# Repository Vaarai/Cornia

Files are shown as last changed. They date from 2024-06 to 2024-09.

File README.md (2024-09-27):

<h1 align="center">
 
</h1>

# Cornia keyboard

<h1 align="center">
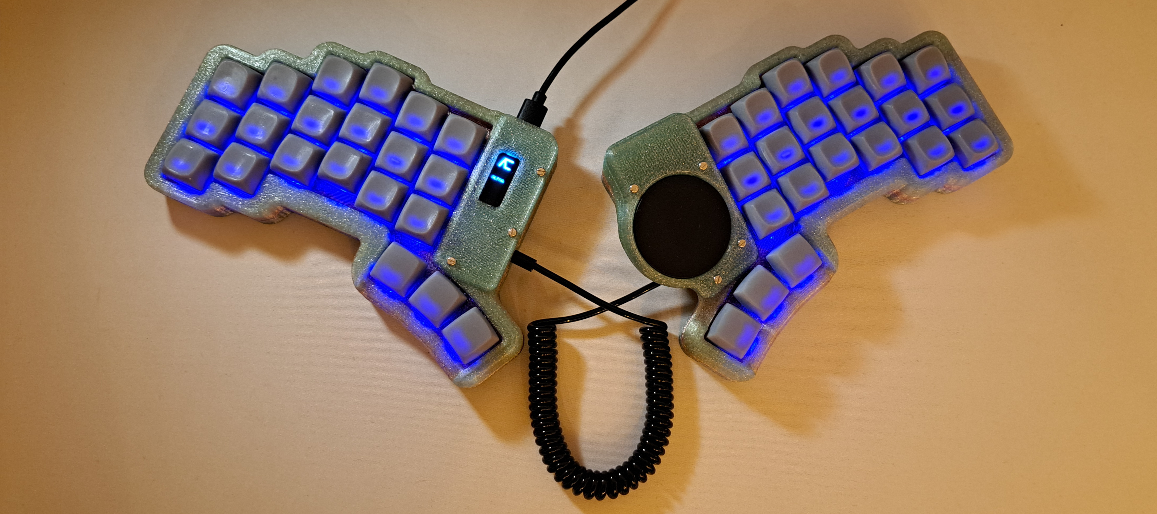
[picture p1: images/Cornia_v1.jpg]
 
</h1>

The Cornia keyboard is a split keyboard featuring : 
* 3x6 column strongly staggered keys and 3 thumb keys
* Hotswap sockets (Compatible with Kailh and Gateron)
* All 1u keys
* Same PCB for both hands (revesible)
* No diode to solder (No switch matrix)
* Per key adressable RGB leds (SK6812MINI-E)
* QMK Handedness pin (see [QMK documentation](https://github.com/qmk/qmk_firmware/blob/master/docs/config_options.md#setting-handedness))

### Why this name ?

Because it was inspired from the [Corne](https://github.com/foostan/crkbd/tree/main) keyboard, and `Cornia` came in mind.

### Table of contents

<!--ts-->
  * [Quick steps](#quick-steps)
  * [Hardware](#hardware)
    * [Bill of material](#bill-of-material)
    * [Compatible controllers](#compatible-controllers)
    * [PCB Design](#pcb-design-and-manufacturing)
    * [Keyboard assembling](#keyboard-assembling)
    * [Troubleshooting](#troubleshooting)
  * [Software](#software)
    * [Cornia not yet integrated in official QMK ?](#cornia-not-yet-integrated-in-official-qmk)
    * [Keymap](#keymap)
  * [Case](#case)
  * [Photos](#photos)
<!--te-->

# Quick steps

1. [Order the PCB](./doc/pcb_ordering.md)
2. [Print the case](https://www.printables.com/model/958200-case-for-cornia-v1-including-a-trackpad-version-40)
3. [Assemble/solder PCB](./doc/assembly_guide.md)
4. [Flash Cornia QMK](https://github.com/Vaarai/qmk_firmware/tree/cornia/keyboards/cornia)

# Hardware

### Bill of material

| Name | Count | Remarks |
|:-|:-|:-|
| PCB | 2 | [PCB Ordering guide](./doc/pcb_ordering.md) |
| OLED Display | 2 | |
| [RP2040 ProMicro](https://keeb.io/products/rp2040-pro-micro-usb-c-controller) | 2 | Alternative: Refer to [Compatible controllers](#compatible-controllers) |
| TRRS 3.5mm jack | 2 | Ref: PJ-320A |
| Reset switch | 2 | SMD 4x4mm |
| I²C Pull-up resistors | 2 | 0805 form-factor and any value between 2.2kΩ and 4.7kΩ |
| Handedness Pull-up/down resistor | 1 | 0805 form-factor and any value between 2.2kΩ and 4.7kΩ |
| Hotswap sockets | 42 | Compatible with Kailh and Gateron |
| Key switches | 42 | Only compatible with MX style |
| Keycaps | 42 | 1u size |
| TRRS (4 poles) cable | 1 | |
| USB cable | 1 | USB Micro or USB-C depending on the controller, avoid charge-only cables |
| Case | 2 | [Cornia v1 Printables](https://www.printables.com/model/958200-case-for-cornia-v1-including-a-trackpad-version-40) |

### Compatible controllers

| Reference | I²C OLED Display | Handedness pin | Other features |
|:-|:-:|:-:|:-:|
| [RP2040 Aliexpress](https://fr.aliexpress.com/item/1005005980167753.html) | $${\color{green}✓}$$ | $${\color{green}✓}$$ | $${\color{green}✓}$$ |
| [RP2040 keeb.io](https://keeb.io/products/rp2040-pro-micro-usb-c-controller) | $${\color{green}✓}$$ | $${\color{green}✓}$$ | $${\color{green}✓}$$ |
| [0xCB-Helios](https://github.com/0xCB-dev/0xCB-Helios) | $${\color{green}✓}$$ | $${\color{green}✓}$$ | $${\color{green}✓}$$ |
| [Elite-Pi](https://docs.keeb.io/elite-pi-guide) | $${\color{red}⨯}$$ | $${\color{red}⨯}$$ | $${\color{green}✓}$$ |
| [RP Micro](https://github.com/siderakb/rp-micro) | $${\color{red}⨯}$$ | $${\color{red}⨯}$$ | $${\color{green}✓}$$ |

### PCB design and manufacturing

Schematic and PCB views are available in `pdf/`:
- [Schematic](pdf/SCH.pdf)
- [PCB Top view](pdf/PCB_TOP.pdf)
- [PCB Bottom view](pdf/PCB_BOT.pdf)

To manufacture the Cornia PCB please follow the [PCB manufacturing guide](./doc/pcb_ordering.md)

In case you want to modify the PCB please take a look at the following:
- KiCad [project description](./PCB/README.md)
- Export bash script to ease the process, it is documented in [Manufacturing files export guide](./doc/manufacturing_files_export.md)

### Keyboard assembling

To solder and assemble the Cornia keyboard please follow the [Cornia assembly guide](./doc/assembly_guide.md)

### Troubleshooting

[Troubleshooting guide](./doc/troubleshooting_pcb.md)

# Software

Cornia keyboard firmware is based on QMK.

### Cornia not yet integrated in official QMK ?

If Cornia keyboard not yet integrated in [qmk_firmware](https://github.com/qmk/qmk_firmware) you can go to [Vaarai QMK fork](https://github.com/Vaarai/qmk_firmware/tree/cornia/keyboards/cornia) on and follow the readme.

### Keymap

- [Default QWERTY layout for Cornia keyboard](https://www.keyboard-layout-editor.com/#/gists/5af136790cefe4b35cdf02ca52c1fccc)
- [Fire layout for Cornia keyboard](https://www.keyboard-layout-editor.com/#/gists/a40345c92e1f3f326426ef890ebf4d1c) (Based on [Fire (Oxey)](https://bit.ly/layout-doc-v2) layout)

# Case

Case for Cornia v1 is available on [Cornia v1 Printables](https://www.printables.com/model/958200-case-for-cornia-v1-including-a-trackpad-version-40) from user Rikiki, optionally including a trackpad version (40mm) available for both halves.

Cornia keyboard is a project initiated by a post from `help-forum` on [QMK Discord](https://discord.gg/qmk).

User Rikiki requested in this post if someone could alter [crkbd](https://github.com/foostan/crkbd) PCB to match his requirements.

I (Vaarai) replied to this post and in 1 months we made 2 iterations of crkbd variant and it diverged from crkbd in a way that we started to make a new keyboard and 5 months later it lead to the Cornia.

Rikiki made all the mechanical parts and I designed the PCB then developed a QMK implementation.

# Photos

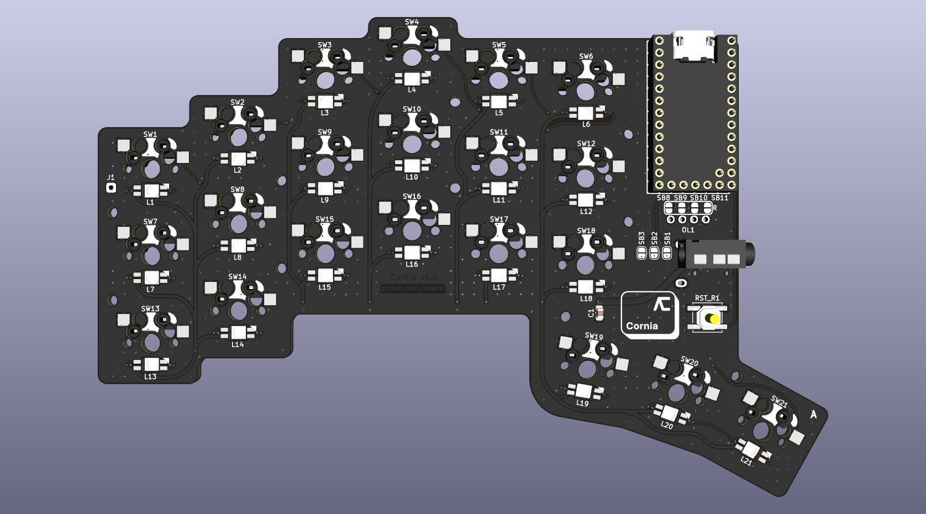
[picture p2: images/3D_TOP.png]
3D Top view

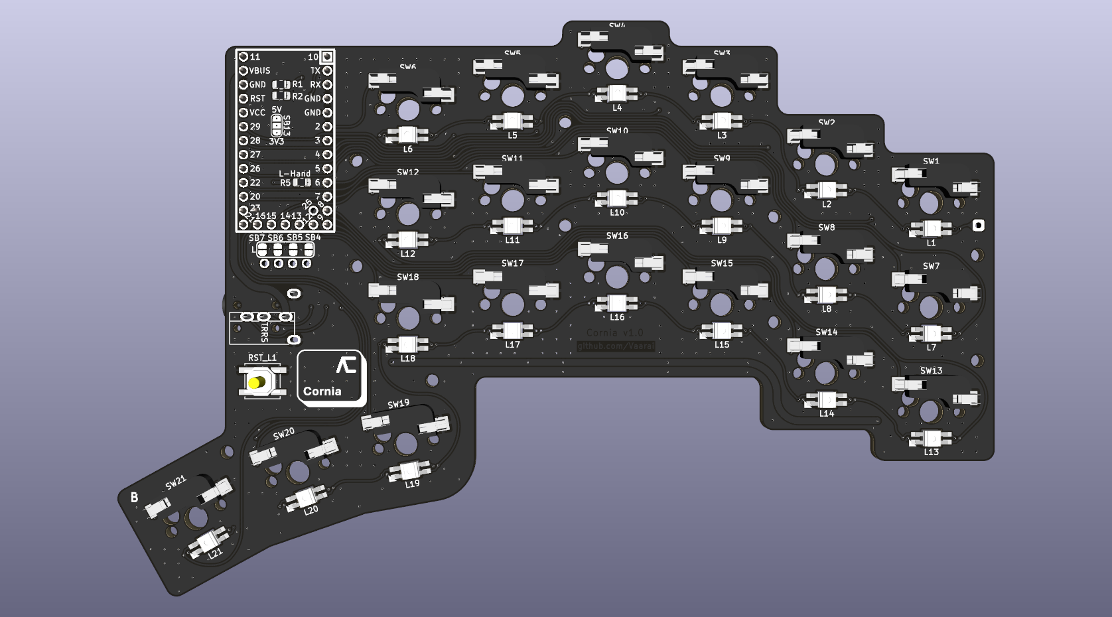
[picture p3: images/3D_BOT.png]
3D Bottom view


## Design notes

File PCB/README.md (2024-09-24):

# Cornia KiCad project overview

This KiCad project is designed for the Cornia keyboard PCB

## KiCad files Descriptions

- __cornia.kicad_pro:__ This is the main project file for KiCad. It contains general information about the project, such as library paths, and links to schematic and PCB files.
- __cornia.sch:__ This file defines the circuit diagram and component connections.
- __cornia.kicad_pcb:__ This file contains the PCB layout, including component placement, routing, and layer definitions.
- __cornia.kicad_sym:__ This file defines the symbol for a custom component used in the schematics.
- __cornia.kicad_mod:__ This file defines the footprint for a custom component used in the PCB layout.
- __cornia.pdf:__ This file contains any relevant documentation or information about the project.

## Usage
- __Open the project:__ Launch KiCad and open __cornia.kicad_pro__ file.
- __View schematics:__ Open schematic file from the project view.
- __Inspect PCB layout:__ Open PCB layout file from the project view.
- __Modify as needed:__ Make any necessary changes to the schematics and/or PCB layout.
- __Generate Gerber files:__ If you're ready to manufacture the PCB, generate the Gerber files from the PCB layout.

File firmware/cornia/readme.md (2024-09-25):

# Cornia Keyboard

![Cornia]()

A split keyboard with 3x6 column strongly staggered keys and 3 thumb keys

Keyboard Maintainer: [Vaarai](https://github.com/Vaarai) 
Hardware Supported: Cornia PCB, RP2040 / 0xCB-Helios
Hardware Availability: [PCB Data](https://github.com/Vaarai/Cornia)

Make example for this keyboard (after setting up your build environment):
```sh
    make cornia:default
```

Flashing example for this keyboard:
```sh
    make cornia:default:flash
```

See the [build environment setup](https://docs.qmk.fm/#/getting_started_build_tools) and the [make instructions](https://docs.qmk.fm/#/getting_started_make_guide) for more information. Brand new to QMK ? Start with our [Complete Newbs Guide](https://docs.qmk.fm/#/newbs).

## Bootloader

The Cornia PCBs have a reset button on the bottom side near to the TRRS jack.

To enter in to the bootloader you can either:
- Hold reset when plugging in that half of the keyboard.
- Double press reset if firmware was already flashed and if RP2040 is used
- Press NAV+NUM+ESC if firmware was already flashed no matter what controller is used

## Disable RGB Matrix

The Corne Keyboard use the RGB Matrix feature by default. To disable it please make with the following command:
```sh
    make cornia/v1_no_led:default
```

And flash with:
```sh
    make cornia/v1_no_led:default:flash
```

## OLED Display & Cirque Trackpad

The Corne Keyboard also support OLED Display and Cirque Trackpad through I²C, an implementation is available in `fire` keymap.

To use it please make with the following command:
```sh
    make cornia:fire
```

And flash with:
```sh
    make cornia:fire:flash
```

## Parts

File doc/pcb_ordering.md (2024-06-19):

# Cornia PCB

The Cornia PCB is designed with 0.25mm track width (0.5mm for VCC, VBUS & GND) and 0.25mm of track clearance.

Below are the constraints of the Design Rules Check (DRC) used in Kicad :

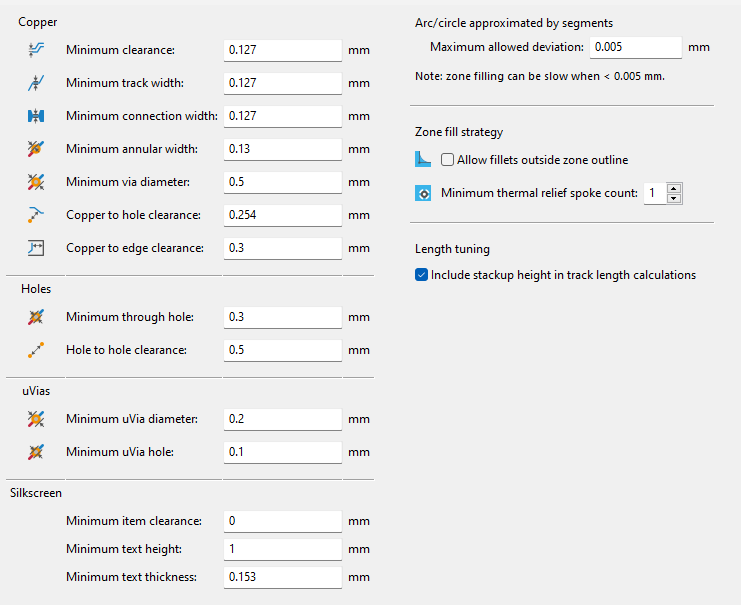
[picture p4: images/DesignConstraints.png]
<h3 align="center"></h3>
<h3 align="center"></h3>

It is fully compliant with the [JLCPCB capabilities](https://jlcpcb.com/capabilities/pcb-capabilities) except for distance between holes of the hotswap socket.

Test was done with JLCPCB manufacturing but the Cornia can be printed with the PCB manufacturer of your choice, just be carefull about their capabilities and compare with the one in the pictures above.

## PCB Order

> **&#9432;**  This guide is based on JLCPCB website at the date it is written, if the interface changed drastically you could open an issue.

> **&#9432;**  For other PCB manufacturer, instructions can be adapted as the process is barely the same.

0. If PCB was modified, please check [Manufacturing files export guide](./manufacturing_files_export.md) 
1. Create a `.zip` with the content of the [gerber/](../gerber/) folder, no matter the name of the zip but `cornia_Vx.x.zip` with `Vx.x` the version used can help to keep track of your work.  
2. Go to [jlcpcb.com](https://jlcpcb.com/) and register then login, or just login if you already have an account.
3. Click on [Instant Quote](https://cart.jlcpcb.com/quote).
    <h3 align="center"></h3>

4. Upload the gerber `.zip` by clicking `Add gerber file` button or drag and drop the `.zip` on the this button. The upload can take a moment before showing the PCB preview.
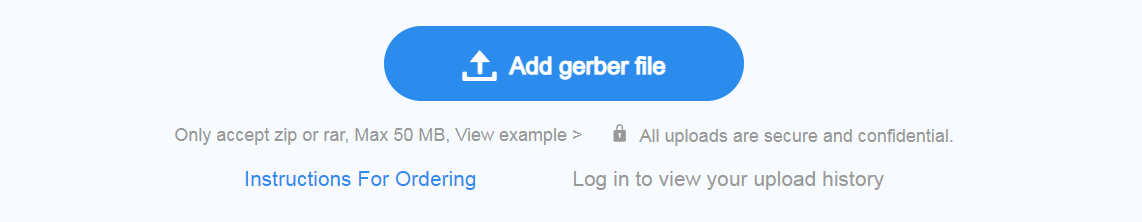
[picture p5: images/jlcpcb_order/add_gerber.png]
    <h3 align="center"></h3>

5. Ensure that the following `PCB Specification` is checked (except for the color, choose the color you want !)
    - Different Design : 1 (only one design in the .zip)
    - Delivery format : Single PCB
    - PCB Thickness : 1.6mm (standard)
    - Surface Finish : HASL with lead (Hot-Air Solder Leveling), other solution are ok but it's the cheapest. 
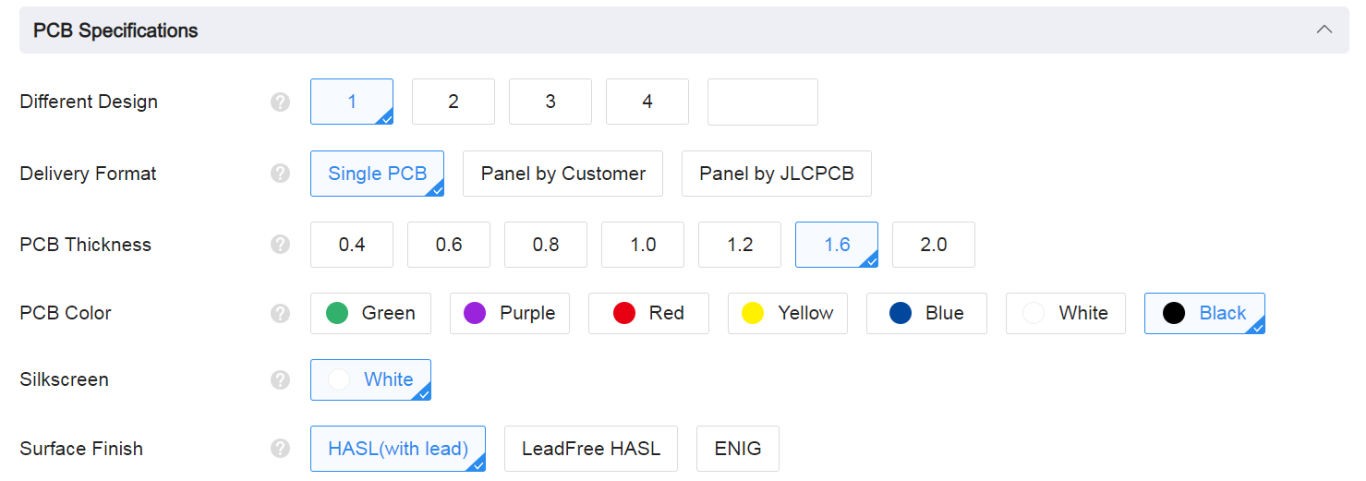
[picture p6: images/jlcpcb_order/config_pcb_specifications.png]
    <h3 align="center"></h3>

6. Ensure that the following `High-spec Options` is checked.
    - Outer Copper Weight : 1oz (standard)
    - Via Covering : Tented
    - Board Outline Tolerance : ±0.2mm (No need for more)
    - Confirm Production file : No (Except if you made some modifications to the design)
    - Remove Order Number : No (or Yes if the price do not matter)
    - Flying Probe Test : Fully Test
    - Gold Fingers : No
    - Castellated Holes : No
    - Edge Plating : No
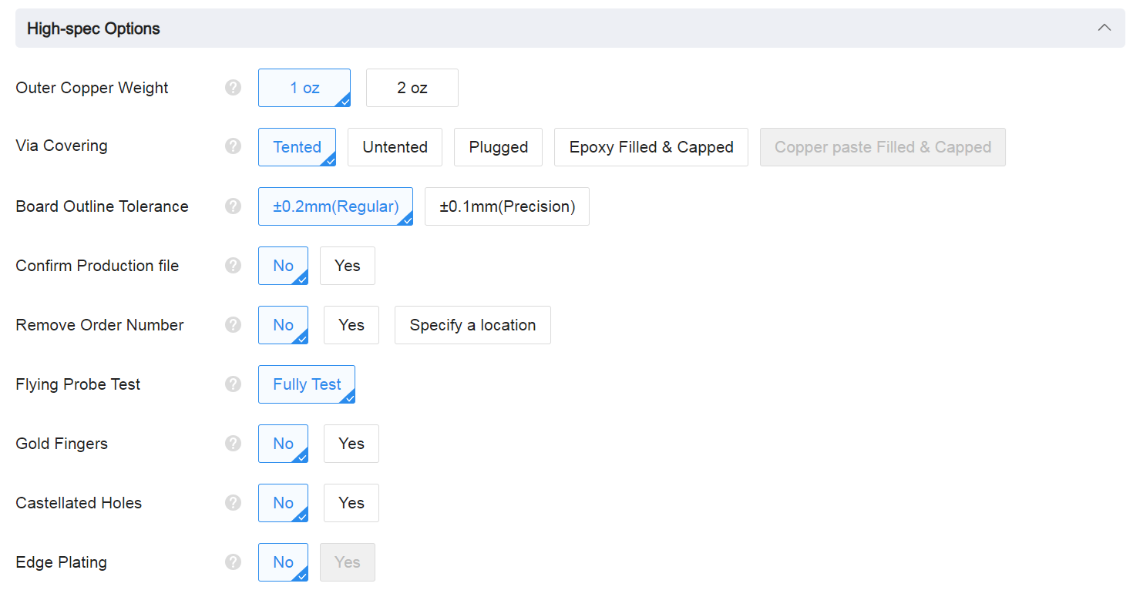
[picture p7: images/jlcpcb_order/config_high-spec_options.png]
    <h3 align="center"></h3>

7. Do not modify the `Advanced Options` tab except you know what you're doing.
8. Choose your shipping method and proceed to checkout.
9. Order other elements from the BOM. 
10. Take a look at the software documentation before the delivery ! &#128513;

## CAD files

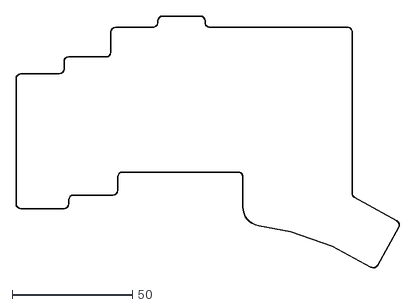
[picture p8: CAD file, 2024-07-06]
case/LaserCut.BOT.dxf
159.6 x 104.7

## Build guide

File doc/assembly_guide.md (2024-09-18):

# Preparation

This guide will help you to assemble your Cornia keyboard following steps below.

## Tools

List of tools required to solder & assemble the Cornia:
- Soldering iron with a relatively thin tip
- Solder wire and flux
- Tweezer to handle small components during the soldering

And below is the tools required to test the soldering: 
- Multimeter or at least continuity tester

Useful documents for the components placement and soldering:
- [PCB schematic](./../pdf/SCH.pdf)
- [Toubleshooting guide](./troubleshooting_pcb.md)

## Parts list

Ensure you get all parts in hand from [Bill of material](./../README.md#bill-of-material)

## PCB Marking

Some marking are present on the PCB to help component placement.
- Faces are noted at the extremity of the thumb cluster (Face `A` or `B`):
    - On the left hand PCB, face noted `A` shall be the top face.
    - On the right hand PCB, face noted `B` shall be the top face.
- All components are labeled to identify them both on schematic and PCB :
    - `SWx` : Keyboard switches including hotswap socket
    - `Lx` : Per key RGB led
    - `SBx` : Solder bridges used to cunfigure the board
    - `Rx` : Resistors
    - `RSTx` : Reset button (solder `RST_Lx` for left and `RST_Rx` for right hand)
    - `TRRS` : TRRS connector
    - `OLx` : OLED Display
    - `Cx` : Capacitor
    - `Jx` : Test point
- Additionnal labels are present to help with the configuration:
    - `SB4` to `SB11` are grouped and labeled `L` or `R` to distinguish left hand and right hand configuration
    - `SB12` and `SB13` are labeled with the voltage to configure on the I²C bus (`5V` or `3V3`)
    - `R5` and `R6` are labeled `L-Hand` and `R-Hand` to configure the [QMK handedness](https://docs.qmk.fm/features/split_keyboard#handedness-by-pin)

# Soldering

## Quick steps by steps

### Left hand PCB
[***STEP 1***](#solder-bridges) - Solder `SB4` to `SB7`</br>
[***STEP 2***](#solder-bridges) - Solder `SB13` according to desired OLED display voltage</br>
[***STEP 3***](#resistors) - Solder `R5` with 0805 resistor from 2.2KΩ to 4.7kΩ</br>
[***STEP 4***](#hotswap-socket) - Solder all hotswap socket on face noted `B`</br>
[***STEP 5***](#rgb-leds) - Solder all RGB leds on face noted `B` (pay attention to the mark)</br>
[***STEP 6***](#reset) - Solder `RST_L1` Reset button</br>
[***STEP 7***](#trrs) - Solder TRRS connector on face noted `A`</br>
[***STEP 8***](#microcontroller-rp2040) - Solder microcontroller board facing down on face noted `A`</br>
[***STEP 9***](#oled-display) - Solder OLED display connector on face noted `A`</br>

### Right hand PCB
[***STEP 1***](#solder-bridges) - Solder `SB8` to `SB11`</br>
[***STEP 2***](#solder-bridges) - Solder `SB12` according to desired OLED display voltage</br>
[***STEP 3***](#resistors) - Solder `R6` with 0805 resistor from 2.2KΩ to 4.7kΩ</br>
[***STEP 4***](#hotswap-socket) - Solder all hotswap socket on face noted `A`</br>
[***STEP 5***](#rgb-leds) - Solder all RGB leds on face noted `A` (pay attention to the mark)</br>
[***STEP 6***](#reset) - Solder `RST_L1` Reset button</br>
[***STEP 7***](#trrs) - Solder TRRS connector on face noted `B`</br>
[***STEP 8***](#microcontroller-rp2040) - Solder microcontroller board facing down on face noted `B`</br>
[***STEP 9***](#oled-display) - Solder OLED display connector on face noted `B`</br>

## Surface mount components

General idea on component placement is to solder all surface mount components on the bottom side of the PCB:
- For the left hand, PCB surface components are soldered on face noted `B`
- For the right hand, PCB surface components are soldered on face noted `A`

### Solder bridges

Solder bridges `SB4` to `SB11` allows the OLED screen to be solder on both sides (for left and right):
- For left hand PCB please solder `SB4` to `SB7`
- For right hand PCB please solder `SB8` to `SB11`

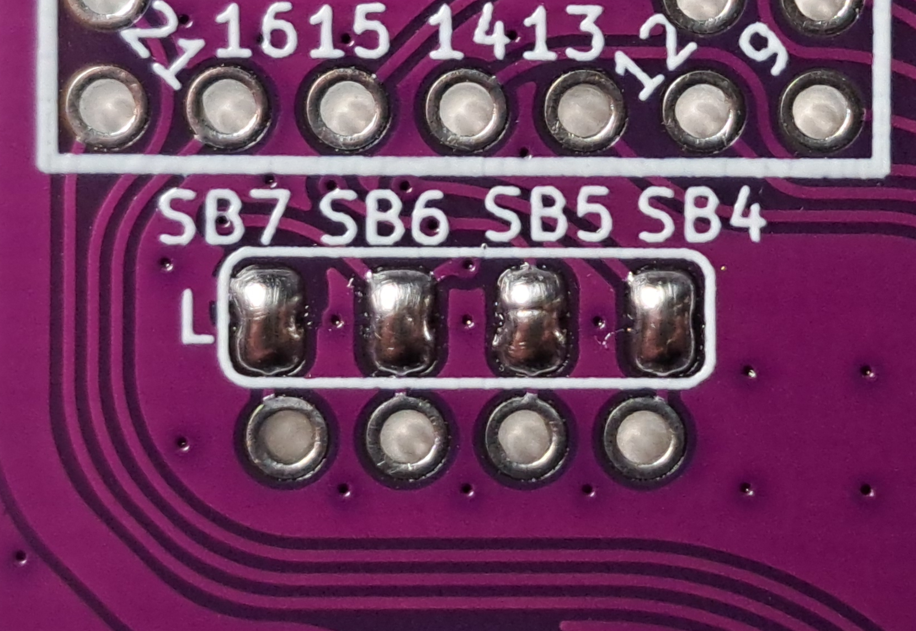
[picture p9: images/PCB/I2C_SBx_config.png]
I²C Solder bridges config


Solder bridges `SB12` and `SB13` allows OLED display voltage settings (I²C bus):
- On left hand, use `SB13`
- On right hand, use `SB12`

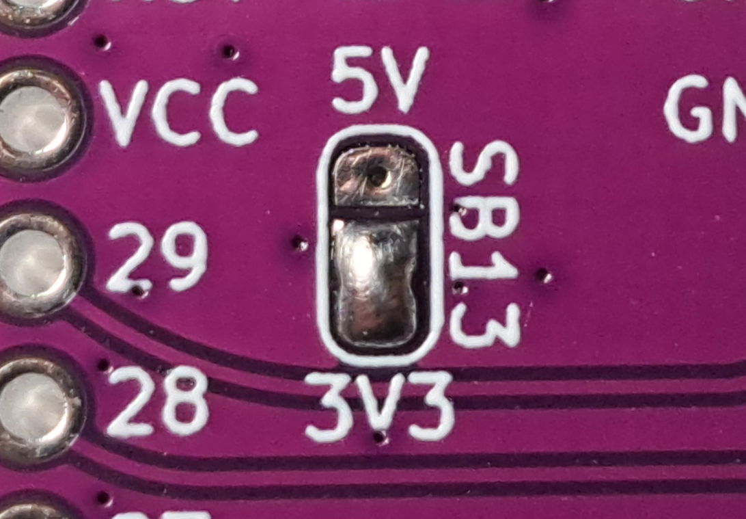
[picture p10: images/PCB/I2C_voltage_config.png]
I²C Voltage config


The voltage to select on the I²C depends on display used, standard one is 5V but please take a look at `Vcc` value in the display datasheet.

To configure a voltage on I²C please solder together 2 pads on the 3 availables, nearest to desired voltage label.

> **_WARNING:_**  Be sure to not solder 3 pads together or 2 pads on one side of the PCB and other 2 pads on the other side. You can test continuity between `SB12` or `SB13` extremity pads.

> **_NOTE:_**  `SB1` to `SB3` shall not be modified except you know what you are doing. (These solder bridges allow to modify the protocol between two halves OR mirror the leds on both sides and free a microcontroller pin on one side)

### Resistors

`R1` and `R2` on the right hand PCB and `R3` and `R4` on the left hand PCB are optional I²C pull-up. These pull-up should not be necessary as majority of OLED deplays embed their own.

I²C Pull-up

`R5` and `R6` are used to configure the [QMK handedness](https://docs.qmk.fm/features/split_keyboard#handedness-by-pin), please solder:
- `R5` on the left hand PCB
- `R6` on the right hand PCB

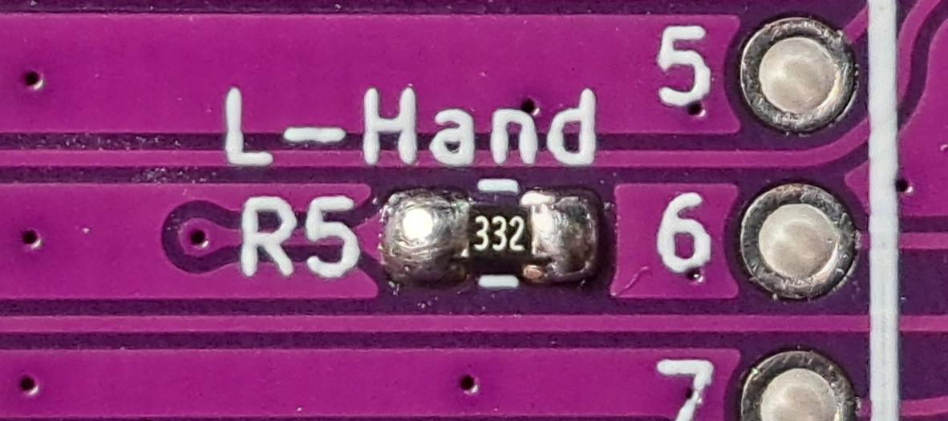
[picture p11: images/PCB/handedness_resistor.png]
QMK handedness resistor


### Hotswap socket

Hotswap socket shall be soldered on face noted `A` for the left hand PCB and on face noted `B` for the right hand PCB

 Top (Left hand, face A) | Bottom (Left hand, face B)
:----------------------:|:-------------------------:
Hotswap socket top view | Hotswap socket bottom view

### RGB leds

RGB leds shall be soldered on face noted `B` for the left hand PCB and on face noted `A` for the right hand PCB.
A mark on the led should be visible and aligned with the mark on the PCB during the placement.

 Top (Left hand, face A) | Bottom (Left hand, face B)
:----------------------:|:-------------------------:
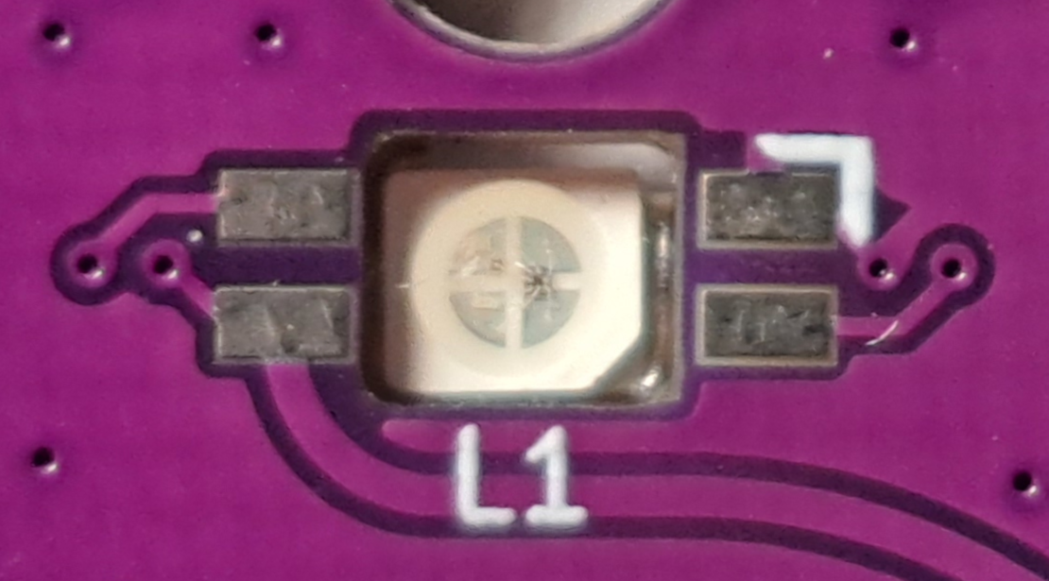
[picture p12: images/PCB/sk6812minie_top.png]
RGB leds top view
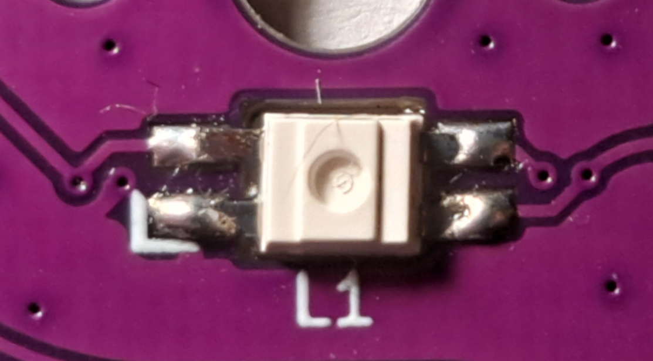
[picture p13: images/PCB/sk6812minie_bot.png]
RGB leds bottom view
 | 

### Reset

Reset button need to be soldered on `RST_L1` for left hand PCB and on `RST_R1` for right hand PCB.
> **_NOTE:_**  On Cornia v1 RC3 the reset button marking is reversed (design mistake) so `RST_L1` for right hand and `RST_R1` for left hand, this is fixed in the v1.

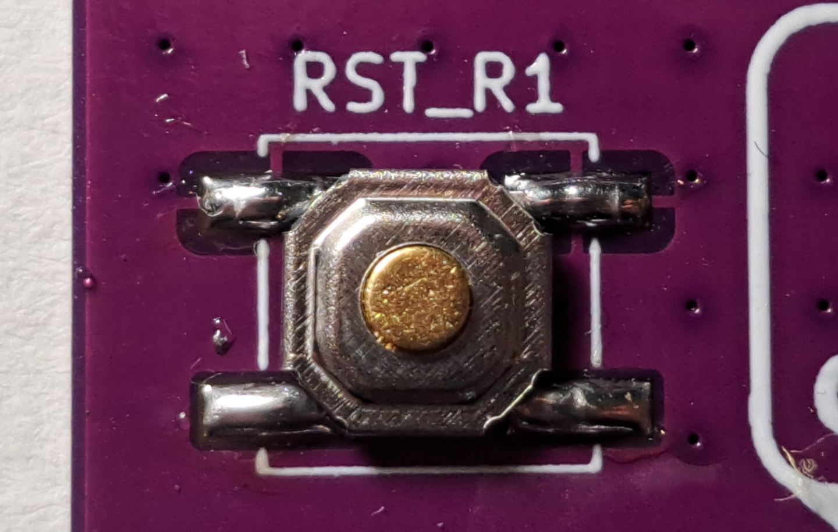
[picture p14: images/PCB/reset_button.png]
Reset button


## Throughole components

### TRRS

TRRS Connector need to be placed on face noted `A` on the left hand PCB and on face noted `B` on the right hand PCB

 Top (Left hand, face A) | Bottom (Left hand, face B)
:----------------------:|:-------------------------:
TRRS Connector top view | TRRS Connector bottom view

### Microcontroller (RP2040)

On the left hand PCB, microcontroller board need to be placed on face noted `A` and microcontroller facing up (visible)

On the right hand PCB, microcontroller board need to be placed on face noted `B` and microcontroller facing down (not visible)

Two option are allowed:
- The microcontroller board can be soldered directly to the keyboard PCB through some pin headers
- The microcontroller board can be plugged to the keyboard PCB through some hotswap pins

RP2040 Hotswap headers view

### OLED Display

OLED Display need to be placed on face noted `A` on the left hand PCB and on face noted `B` on the right hand PCB

OLED Display headers view

# Test

Before assembling the case some test are needed to ensure there is no issue with soldering.   

## Visual inspection

First test is really simple, take a look at each solder joint and see if there is any crack or issue with the joint. 

## Continuity test

If you have access to a multimeter or at least a continuity tester, you should test some of the connections.

## Dummy software test

Load the default binary provided on the Cornia firmware github and test each keys, look at the OLED display and RGB leds if they are working well.
If any issue appear, go through [troubleshooting guide](./troubleshooting_pcb.md).

# Case assembly

**_TODO_**

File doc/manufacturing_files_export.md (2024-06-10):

# Manufacturing files export

To ease the manufacturing files export from Kicad this process is automated using [export_fab_output.sh](../export_fab_output.sh) bash script.

This script perform 5 actions:
- Check PCB DRC (DRC report is saved [here](../PCB/cornia-drc.report))
- Export .dxf files for laser cutted case
- Export .step model of the PCB and assembled components
- Export .pdf of schematic, PCB Top and Bottom views 
- Export gerber, drill & map files for PCB manufacturing

To run this script on Windows it is necessary to have [git-bash](https://www.git-scm.com/download/win).

On Linux this script need to be updated to call the kicad-cli binary instead of the .exe expected on Windows.

It may be necessary to add execution right to the script by running `chmod +x export_fab_output.sh`

> **&#9432;**  Kicad 8 or later is mandatory to use the export in CLI 

## Design Rules Check (DRC)

DRC is a mandatory step before any file exportation to ensure the design rules compliancy

```bash
kicad-cli pcb drc -o cornia-drc.report --all-track-errors --schematic-parity --severity-error --severity-warning --exit-code-violations cornia.kicad_pcb
```

## Export Schematic and PCB top and bottom views 

Schematic and PCB views are useful for the  review process and can be exported using the following command

``` bash
kicad-cli sch export pdf -o pdf/SCH.pdf cornia.kicad_sch && \
kicad-cli pcb export pdf -o pdf/PCB_TOP.pdf -l F.Cu,F.Paste,F.Silkscreen,F.Mask,Edge.Cuts --exclude-value cornia.kicad_pcb && \
kicad-cli pcb export pdf -o pdf/PCB_BOT.pdf -l B.Cu,B.Paste,B.Silkscreen,B.Mask,Edge.Cuts --exclude-value cornia.kicad_pcb
```

## Export DXF for laser cutted case

PCB layers `User.8` & `User.9` are respectively used in cornia footprint & pcb to export DXF for a laser cutted case using the following command

``` bash
kicad-cli pcb export dxf -o case/LaserCut.TOP.dxf -l User.8 --ou mm cornia.kicad_pcb
kicad-cli pcb export dxf -o case/LaserCut.BOT.dxf -l User.9 --ou mm cornia.kicad_pcb
```

## Export `.step` 3D model

PCB and assembled components are 3D modeled and can be exported in step format using the following command

```bash
kicad-cli pcb export step -o case/PCB.step --subst-models cornia.kicad_pcb
```

## Export Gerber for JLCPCB

Based on JLCPCB [kicad export](https://jlcpcb.com/help/article/362-how-to-generate-gerber-and-drill-files-in-kicad-8) recommendations & [Kicad-CLI](https://docs.kicad.org/8.0/en/cli/cli.html) the following commands allow to export all gerber files (including Drill/Map files).

``` bash
kicad-cli pcb export gerbers -o gerber/ -l F.Cu,B.Cu,F.Paste,B.Paste,F.Silkscreen,B.Silkscreen,F.Mask,B.Mask,Edge.Cuts --exclude-value --no-x2 --no-netlist --subtract-soldermask cornia.kicad_pcb
kicad-cli pcb export drill -o gerber/ --format excellon --excellon-separate-th --generate-map --map-format gerberx2 cornia.kicad_pcb
```

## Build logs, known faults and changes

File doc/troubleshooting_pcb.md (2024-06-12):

# PCB troubleshooting guide

## Prerequisites

- Multimeter with continuity tester
- [PCB Schematic](../pdf/SCH.pdf)
- Patience !

## A key is not working

If one or more keys are not working:

```mermaid
flowchart LR
    EXTRACT_SWITCH[Extract concerned switch]
    EXTRACT_SWITCH --> CHECK_PIN{Is switch pin bent}
    CHECK_PIN -- Bent --> FIX_BENT[Fix bent pin]
    CHECK_PIN -- Pin OK --> CHANGE_SWITCH[Change the switch]
    CHANGE_SWITCH --> CHECK_HOTSWAP{"Reflow (re-solder) socket"}
    CHECK_HOTSWAP -- Solved by reflow --> OK[OK]
    CHECK_HOTSWAP -- Still not working --> TICKET[Really ? open an issue]
```

## Multiple keys are registered when a single one is pressed

If two or more keys are registered when a single one is pressed it can be one of the followings:

- Cheap grab bag kecaps. The keycaps have some plastic injection points that protrude under the next keycap. When pressing the key, the small plastic tab is long/big enough to get caught under and force the second key to go down as well. Remove the keycap and cut the protruding plastic tab and re-install.
- A short between two controller pins. Check the soldering on the controller pins and verify that adjacent pins don't have continuity. If this is the case, remove solder from these pins and re-check for a short.

## A led is not working

If one or more leds are not working:

```mermaid
flowchart LR
    ONLY_ONE{Only one led's not working ?}
    ONLY_ONE -- Yes --> REPLACE_FAULTY["Replace the faulty led(s)"]
    ONLY_ONE -- No --> OPEN_SCH[Open the schematic and\nidentify faulty leds numbers]
    OPEN_SCH --> IS_IN_ORDER{What numbers isn't working ?}
    IS_IN_ORDER -- Random --> REPLACE_FAULTY
    IS_IN_ORDER -- From one number up to the last --> REPLACE_FIRST{Replace the lowest numbered faulty led}
    REPLACE_FIRST -- Solved --> OK[OK]
    REPLACE_FIRST -- Still not working --> ONLY_ONE
```

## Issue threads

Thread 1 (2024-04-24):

[PCB] Fix mounting holes alignment between left and right hand

Vaarai, 2024-04-24:

Closed 2024-05-29.

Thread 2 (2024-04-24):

[PCB] Fix Edge.Cuts & User.Eco2 layers to ensure a fully closed path

Vaarai, 2024-04-24:
Fix Edge.Cuts & User.Eco2 layers to ensure a fully closed path.

During User.Eco2 export as DXF, the path isn't fully closed and need manual post-processing to allow case extrusion.

Vaarai, 2024-06-12:
Layer Edge.Cuts & User.Eco2 no longer used for case anufacturing, now it's User.8 & User.9
But this issue is still opened

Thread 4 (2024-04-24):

[Plate] Add plate manufacturing files

Vaarai, 2024-04-24:
Considering plate manufacturing:
- Add SVG alongside DXF
- Create a kicad plate PCB for FR4 plate
- Add STL plate to allow 3D print it

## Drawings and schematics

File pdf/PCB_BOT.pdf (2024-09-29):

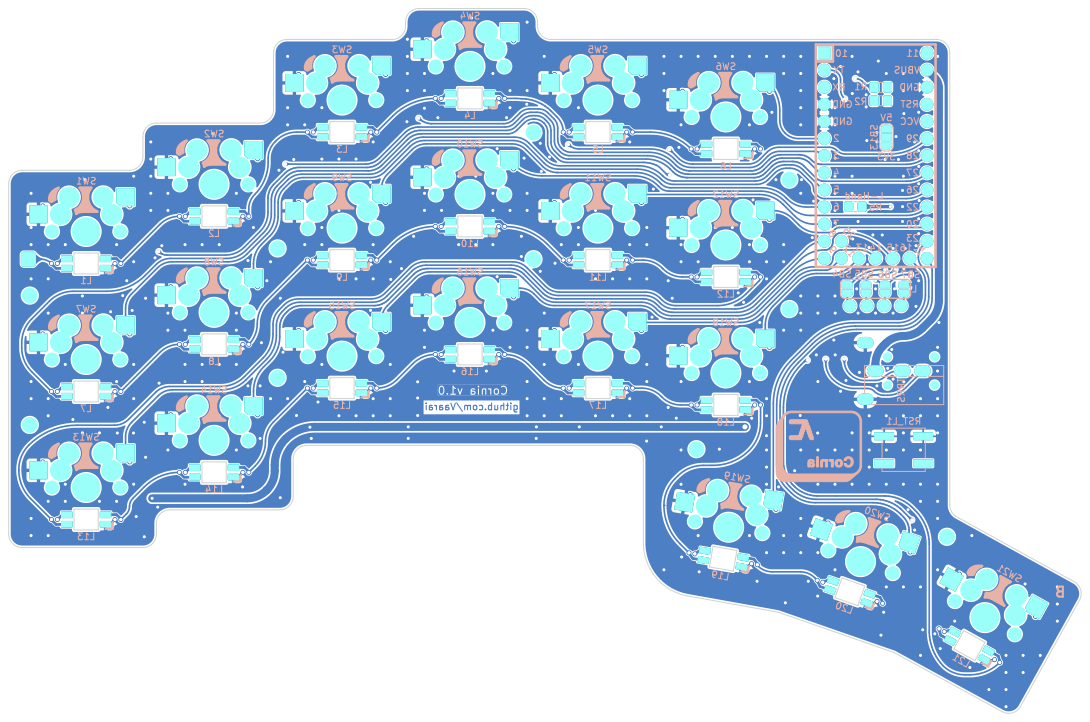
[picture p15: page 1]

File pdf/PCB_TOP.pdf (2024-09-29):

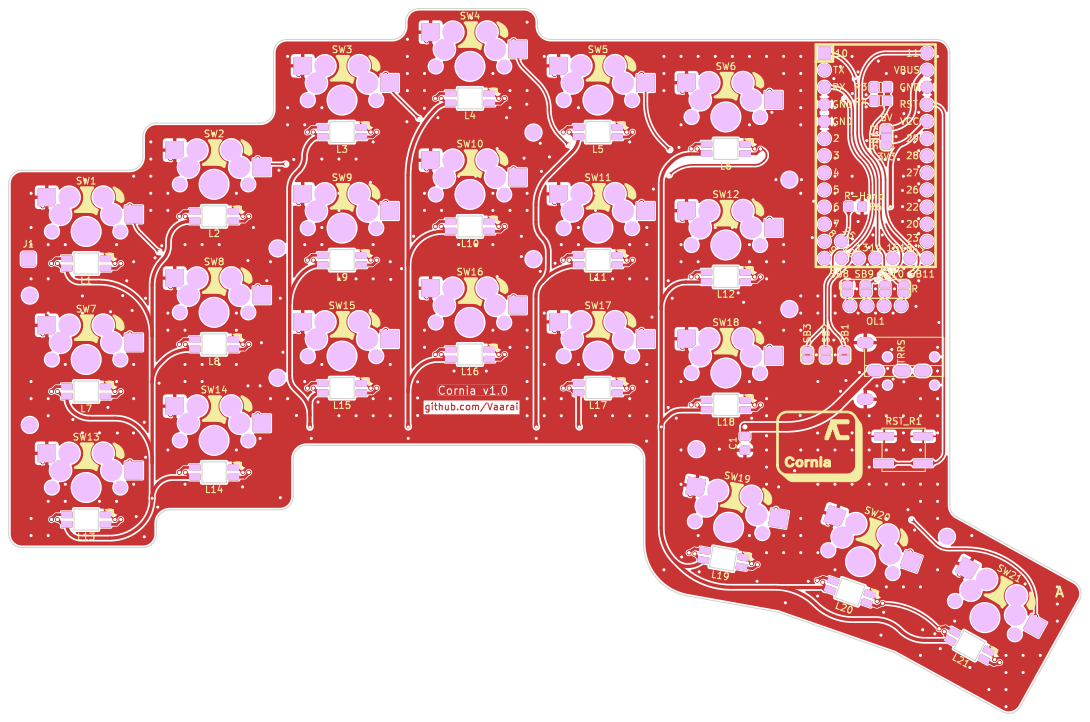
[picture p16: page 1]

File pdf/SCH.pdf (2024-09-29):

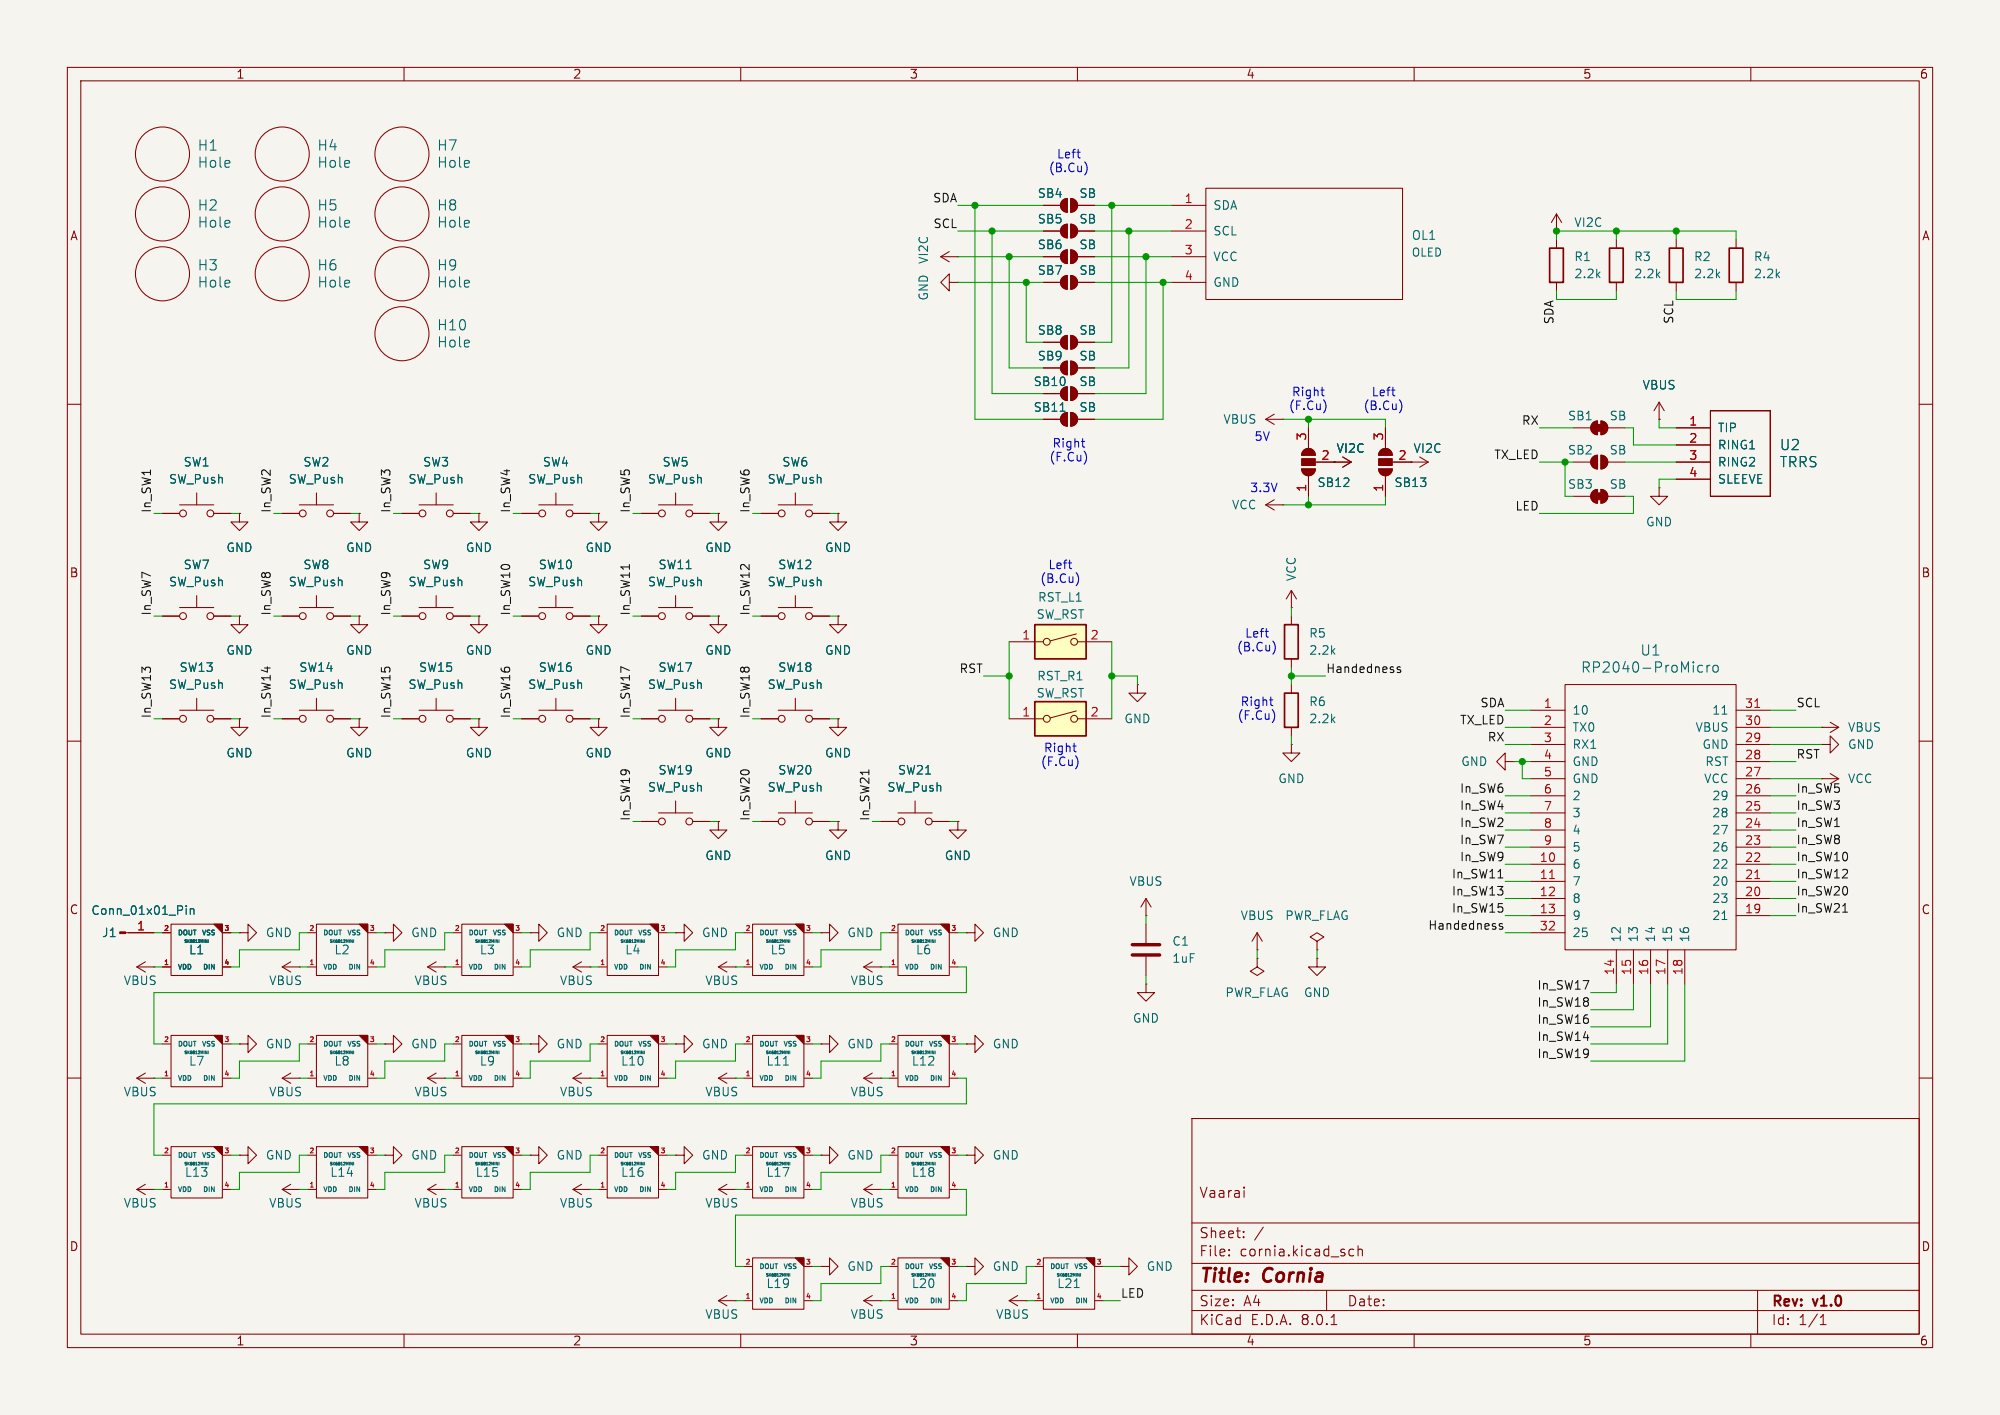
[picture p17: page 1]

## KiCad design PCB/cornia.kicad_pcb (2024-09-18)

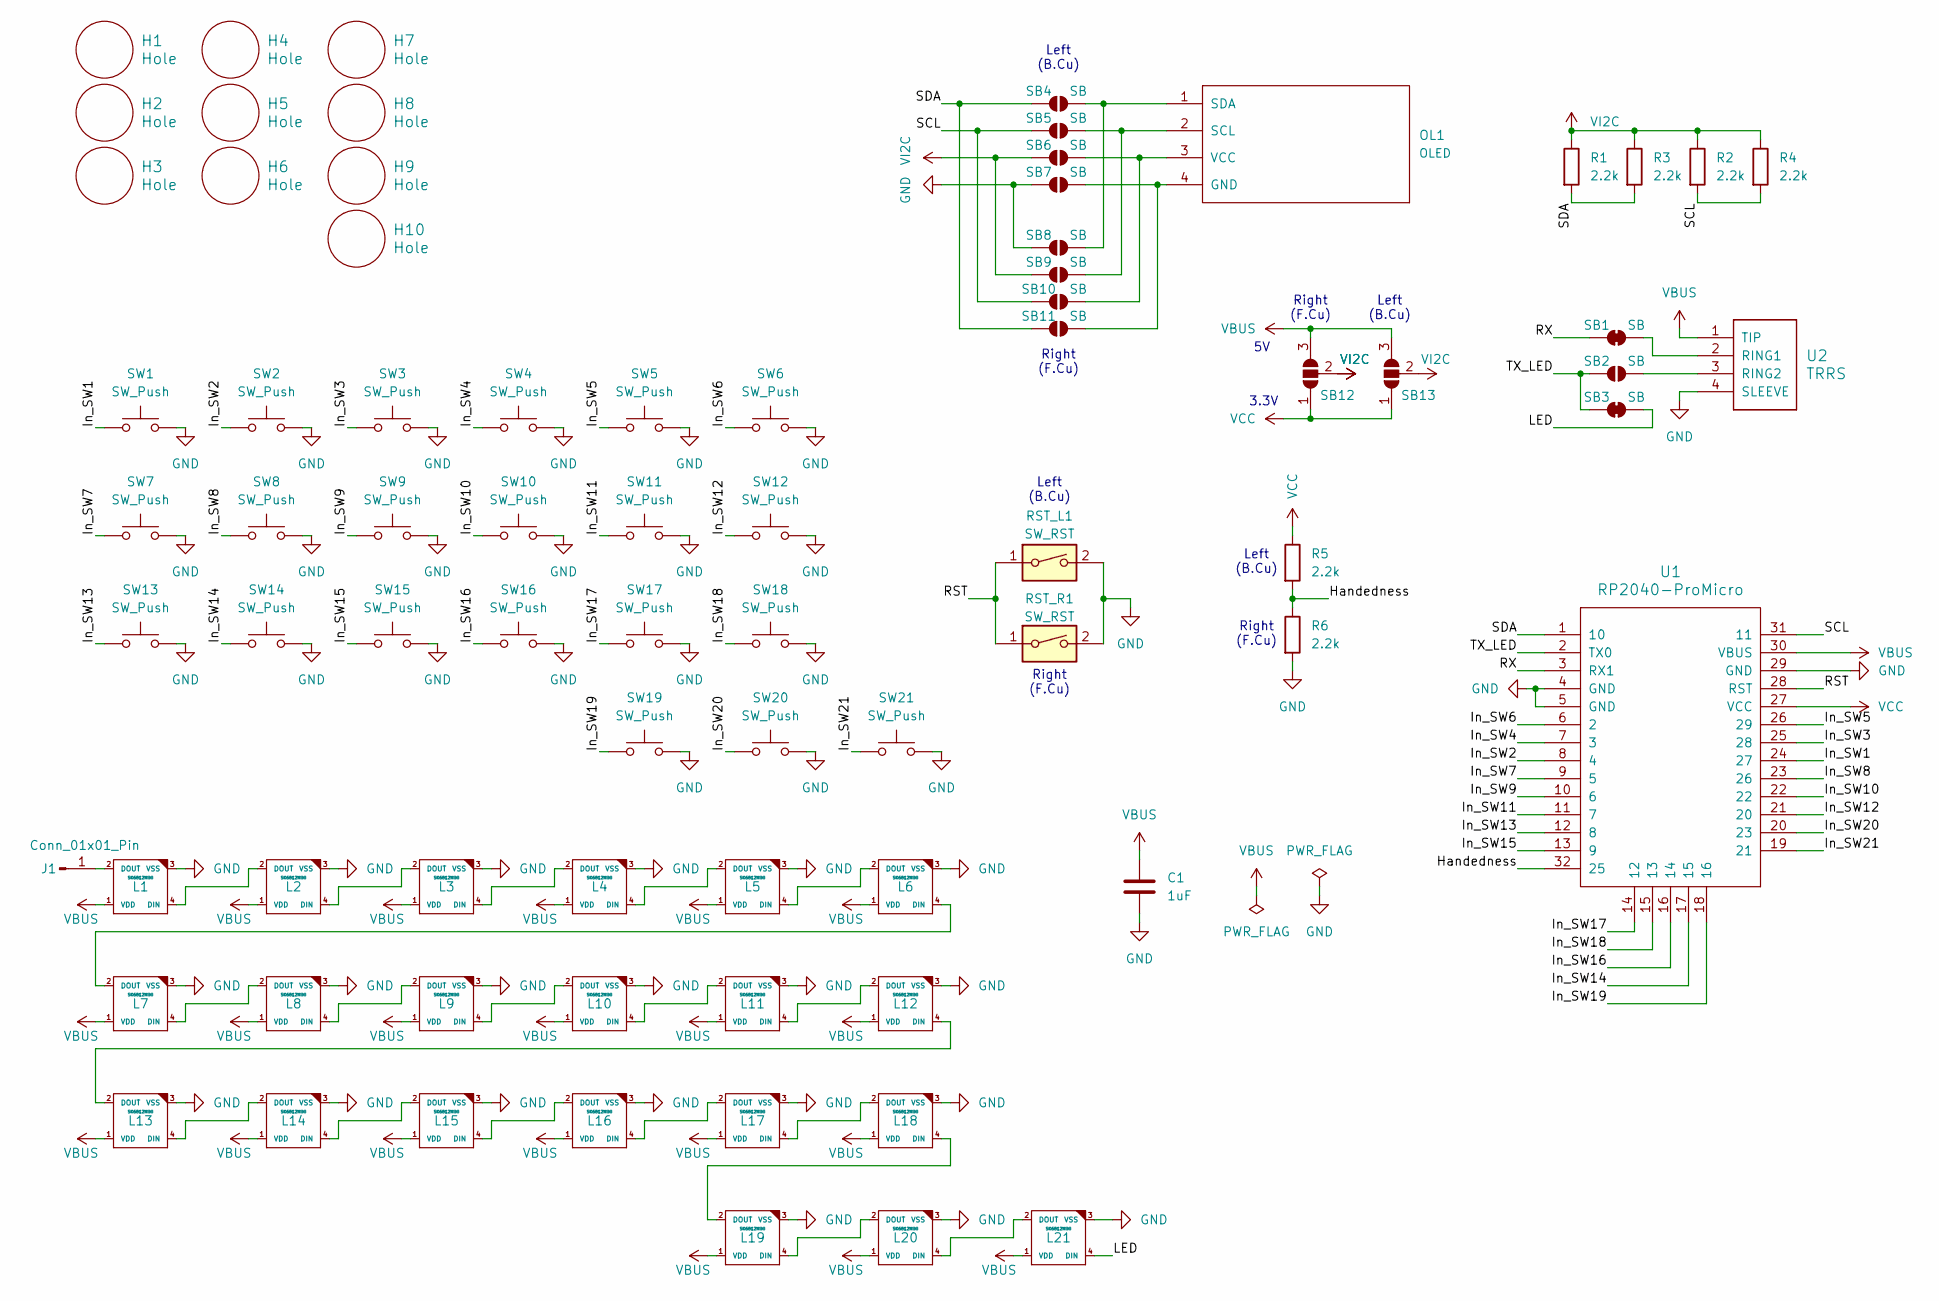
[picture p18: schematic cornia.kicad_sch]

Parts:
C1: 1uF; C_0805
H1, H2, H3, H4, H5, H6, H7, H8, H9, H10: Hole; MountingHole_2.2mm_M2_no_annular
J1: Conn_01x01_Pin; 1Pin
L1, L2, L3, L4, L5, L6, L7, L8, L9, L10, L11, L12, L13, L14, L15, L16, L17, L18, L19, L20, L21: SK6812MINI; YS-SK6812MINI-E
OL1: OLED
R1, R2, R3, R4, R5, R6: 2.2k; R_0805
RST_L1: SW_RST; SW_SMD_4x4mm
RST_R1: SW_RST; SW_SMD_4x4mm
SB1, SB3: SB; SolderJumper-2_Bridged
SB2: SB; SolderJumper-2_Open
SB4, SB5, SB6, SB7, SB8, SB9, SB10, SB11: SB; SolderJumper-2_Open_NoSilk
SB12, SB13: SolderJumper_3_Open; SolderJumper-3_I2C
SW1, SW2, SW3, SW4, SW5, SW6, SW7, SW8, SW9, SW10, SW11, SW12, SW13, SW14, SW15, SW16, SW17, SW18, SW19, SW20, SW21: SW_Push; keyswitch_cherrymx_hotswap_reversible_1u
U1: RP2040-ProMicro
U2: TRRS; TRRS_PJ-320A

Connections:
/Handedness: R5.2, R6.1, U1.32 (25)
/In_SW1: SW1.1, U1.24 (27)
/In_SW2: SW2.1, U1.8 (4)
/In_SW3: SW3.1, U1.25 (28)
/In_SW4: SW4.1, U1.7 (3)
/In_SW5: SW5.1, U1.26 (29)
/In_SW6: SW6.1, U1.6 (2)
/In_SW7: SW7.1, U1.9 (5)
/In_SW8: SW8.1, U1.23 (26)
/In_SW9: SW9.1, U1.10 (6)
/In_SW10: SW10.1, U1.22
/In_SW11: SW11.1, U1.11 (7)
/In_SW12: SW12.1, U1.21 (20)
/In_SW13: SW13.1, U1.12 (8)
/In_SW14: SW14.1, U1.17 (15)
/In_SW15: SW15.1, U1.13 (9)
/In_SW16: SW16.1, U1.16 (14)
/In_SW17: SW17.1, U1.14 (12)
/In_SW18: SW18.1, U1.15 (13)
/In_SW19: SW19.1, U1.18 (16)
/In_SW20: SW20.1, U1.20 (23)
/In_SW21: SW21.1, U1.19 (21)
/LED: L21.4 (DIN), SB3.2 (B)
/RST: RST_L1.1, RST_R1.1, U1.28 (RST)
/RX: SB1.1 (A), U1.3 (RX1)
/SCL: R2.2, R4.2, SB5.1 (A), SB10.1 (A), U1.31 (11)
/SDA: R1.2, R3.2, SB4.1 (A), SB11.1 (A), U1.1 (10)
/TX_LED: SB2.1 (A), SB3.1 (A), U1.2 (TX0)
GND: C1.2, L1.3 (VSS), L2.3 (VSS), L3.3 (VSS), L4.3 (VSS), L5.3 (VSS), L6.3 (VSS), L7.3 (VSS), L8.3 (VSS), L9.3 (VSS), L10.3 (VSS), L11.3 (VSS), L12.3 (VSS), L13.3 (VSS), L14.3 (VSS), L15.3 (VSS), L16.3 (VSS), L17.3 (VSS), L18.3 (VSS), L19.3 (VSS), L20.3 (VSS), L21.3 (VSS), R6.2, RST_L1.2, RST_R1.2, SB7.1 (A), SB8.1 (A), SW1.2, SW2.2, SW3.2, SW4.2, SW5.2, SW6.2, SW7.2, SW8.2, SW9.2, SW10.2, SW11.2, SW12.2, SW13.2, SW14.2, SW15.2, SW16.2, SW17.2, SW18.2, SW19.2, SW20.2, SW21.2, U1.4 (GND), U1.5 (GND), U1.29 (GND), U2.4 (SLEEVE)
unnamed: J1.1, L1.2 (DOUT)
unnamed: L1.4 (DIN), L2.2 (DOUT)
unnamed: L2.4 (DIN), L3.2 (DOUT)
unnamed: L3.4 (DIN), L4.2 (DOUT)
unnamed: L4.4 (DIN), L5.2 (DOUT)
unnamed: L5.4 (DIN), L6.2 (DOUT)
unnamed: L6.4 (DIN), L7.2 (DOUT)
unnamed: L7.4 (DIN), L8.2 (DOUT)
unnamed: L8.4 (DIN), L9.2 (DOUT)
unnamed: L10.4 (DIN), L11.2 (DOUT)
unnamed: L9.4 (DIN), L10.2 (DOUT)
unnamed: L11.4 (DIN), L12.2 (DOUT)
unnamed: L12.4 (DIN), L13.2 (DOUT)
unnamed: L13.4 (DIN), L14.2 (DOUT)
unnamed: L14.4 (DIN), L15.2 (DOUT)
unnamed: L15.4 (DIN), L16.2 (DOUT)
unnamed: L16.4 (DIN), L17.2 (DOUT)
unnamed: L17.4 (DIN), L18.2 (DOUT)
unnamed: L18.4 (DIN), L19.2 (DOUT)
unnamed: L19.4 (DIN), L20.2 (DOUT)
unnamed: L20.4 (DIN), L21.2 (DOUT)
unnamed: OL1.4 (GND), SB7.2 (B), SB11.2 (B)
unnamed: OL1.2 (SCL), SB5.2 (B), SB9.2 (B)
unnamed: OL1.1 (SDA), SB4.2 (B), SB8.2 (B)
unnamed: OL1.3 (VCC), SB6.2 (B), SB10.2 (B)
unnamed: SB1.2 (B), U2.2 (RING1)
unnamed: SB2.2 (B), U2.3 (RING2)
VBUS: C1.1, L1.1 (VDD), L2.1 (VDD), L3.1 (VDD), L4.1 (VDD), L5.1 (VDD), L6.1 (VDD), L7.1 (VDD), L8.1 (VDD), L9.1 (VDD), L10.1 (VDD), L11.1 (VDD), L12.1 (VDD), L13.1 (VDD), L14.1 (VDD), L15.1 (VDD), L16.1 (VDD), L17.1 (VDD), L18.1 (VDD), L19.1 (VDD), L20.1 (VDD), L21.1 (VDD), SB12.3 (B), SB13.3 (B), U1.30 (VBUS), U2.1 (TIP)
VCC: R5.1, SB12.1 (A), SB13.1 (A), U1.27 (VCC)
VI2C: R1.1, R2.1, R3.1, R4.1, SB6.1 (A), SB9.1 (A), SB12.2 (C), SB13.2 (C)

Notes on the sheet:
Right (F.Cu)
Left (B.Cu)
3.3V

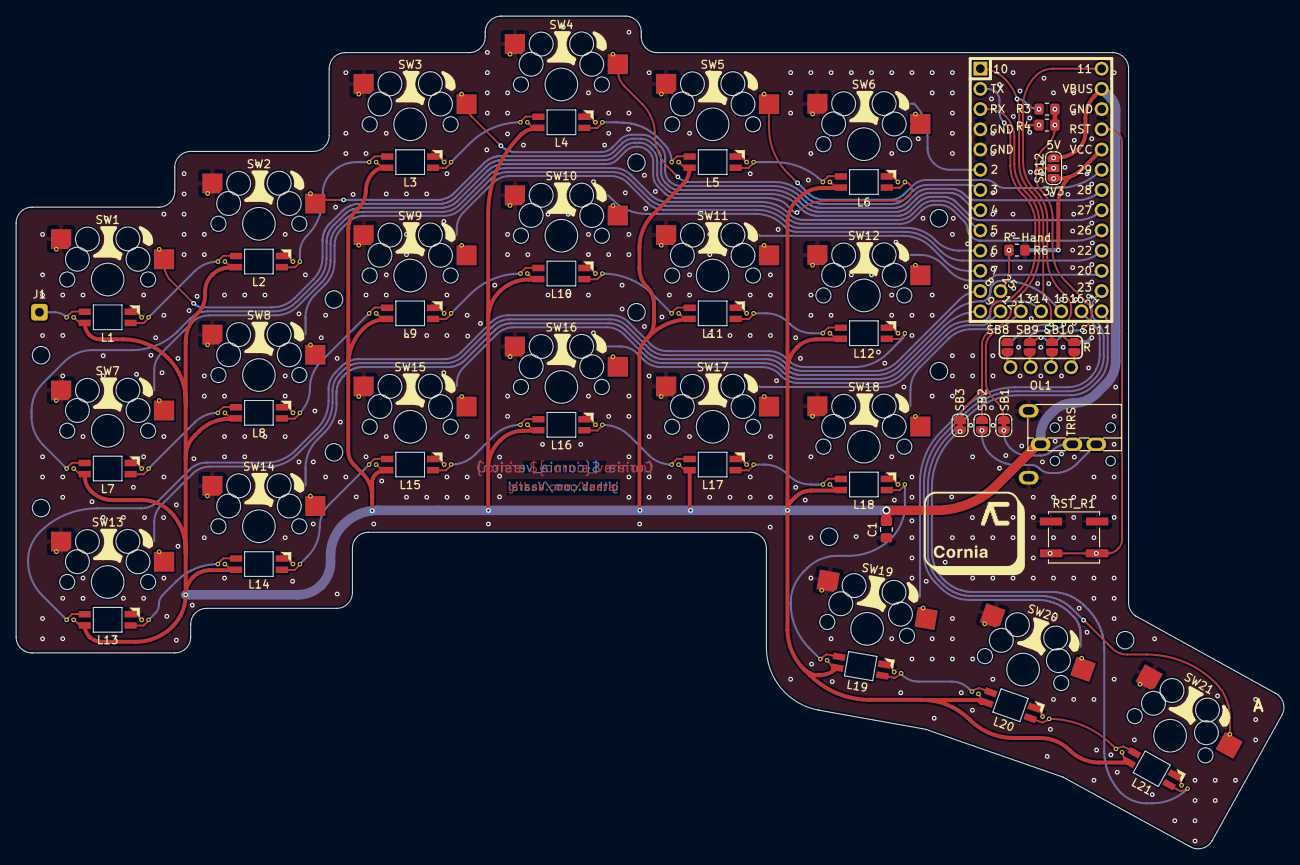
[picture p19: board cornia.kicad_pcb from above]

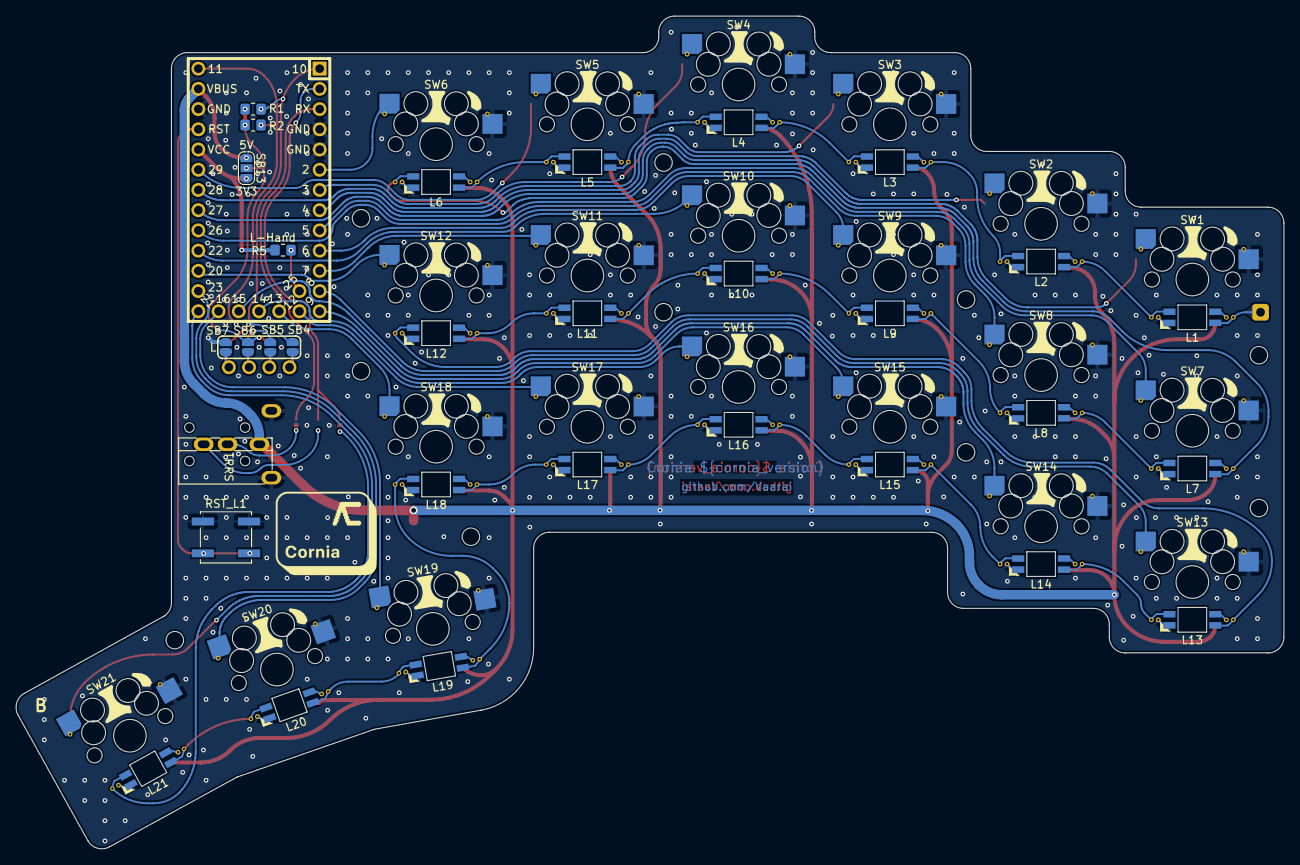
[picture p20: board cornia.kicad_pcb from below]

Board: 2 copper layers, 159.3 x 104.6 mm, 78 parts (9 on the bottom side), 59 nets.

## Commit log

2024-04-23 [PCB] Add mounting hole User.Eco2 layer for dxf export
    [Cornia-PCB-dimensions.dxf, cornia.kicad_pcb]
2024-05-18 [PCB] Remove mounting Hole and give space in front of USB connector
    [cornia-B_Cu.gbl, cornia-B_Mask.gbs, cornia-B_Paste.gbp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]
2024-05-28 First push V1
    [Cornia-PCB-dimensions.dxf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]
2024-05-30 Finish routing & add gerber/case export in CLI
    [LaserCut.BOT.dxf, LaserCut.TOP.dxf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]
2024-05-31 Finish PCB, add fab output, update doc
    [cornia-B_Cu.gbl, cornia-B_Mask.gbs, cornia-B_Paste.gbp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]
2024-06-04 [PCB] Add handedness pin
    [LaserCut.BOT.dxf, LaserCut.TOP.dxf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]
2024-06-08 [PCB] Rework OLED SBx & Add last led DOUT TP
    [LaserCut.BOT.dxf, LaserCut.TOP.dxf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]
2024-06-10 [Tools] Update export script and add .step export
    [cornia-B_Cu.gbl, cornia-B_Mask.gbs, cornia-B_Paste.gbp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]
2024-06-13 [PCB] Move 2mm left MCU/TRRS/RST
    [cornia.kicad_pcb]
2024-06-19 [PCB/Footprint] Remove 5mm mounting hole + update RP2040 & RST 3D
    [cornia.kicad_pcb, cornia.kicad_sch]
2024-06-19 [Output] Update
    [LaserCut.BOT.dxf, LaserCut.TOP.dxf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]
2024-07-06 [PCB/Symbol] Add 10x 2.2mm holes + Add new logo
    [cornia.kicad_pcb, cornia.kicad_sch]
2024-07-06 [PCB/Output] Increase Oled pads diameter + update output
    [cornia-B_Cu.gbl, cornia-B_Mask.gbs, cornia-B_Paste.gbp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]
2024-07-06 [PCB/Output] Add teardrop + update output
    [cornia-B_Cu.gbl, cornia-B_Mask.gbs, cornia-B_Paste.gbp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]
2024-08-29 [Doc] Add assembly guide draft
2024-09-02 [PCB] Fix RGB Led pin assignment mistake
    [cornia.kicad_pcb, cornia.kicad_sch]
2024-09-02 [PCB] Multiple fix based on v1RC2 board bring-up
    - Reduce RST thermal relief width
    - Update SB silkscreen
    - Update TRRS silkscreen
    [cornia.kicad_pcb, cornia.kicad_sch]
2024-09-02 [PCB DRC] Edit 'vias' props in switch and led footprint to avoid SMD/THT DRC confusion
2024-09-02 [PCB DRC] Enable 'hole to hole' DRC and fix all issues
    [cornia.kicad_pcb]
2024-09-02 [PCB] Swap TX RX pins
    [cornia.kicad_pcb, cornia.kicad_sch]
2024-09-18 [PCB] Swap RST_L1 & RST_R1 to match their respective sides
    [cornia.kicad_pcb, cornia.kicad_sch]
2024-09-18 [PCB] Fix handedness pin voltage (fixed to 3v3)
    [cornia.kicad_pcb, cornia.kicad_sch]
2024-09-18 [Doc] Add pictures to assembly guide for SMDs
2024-09-24 [Doc] Add PCB readme
2024-09-27 [Doc] Add case section and link
2024-09-29 [Output] Generate fab output
    [LaserCut.TOP.dxf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]
